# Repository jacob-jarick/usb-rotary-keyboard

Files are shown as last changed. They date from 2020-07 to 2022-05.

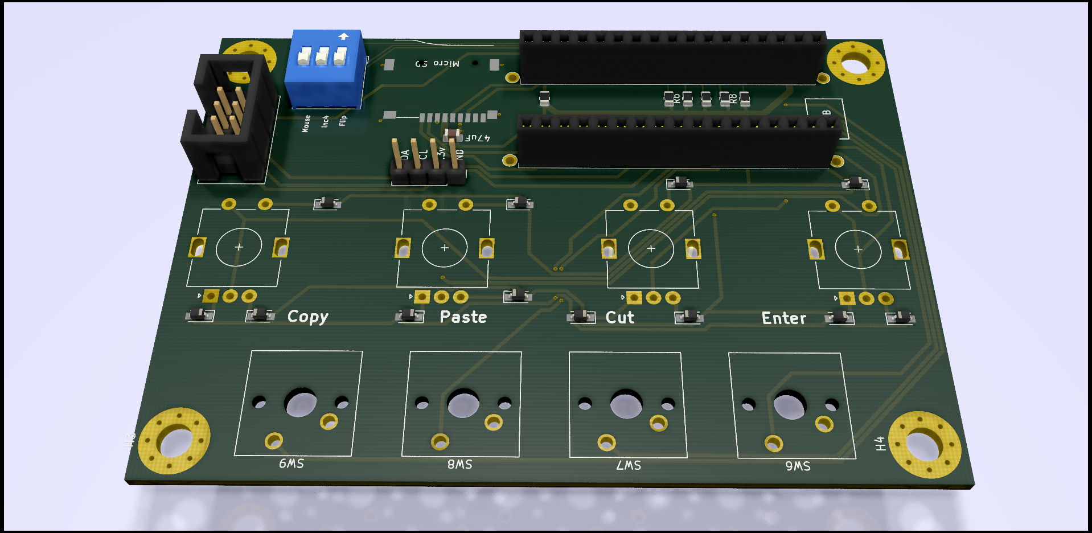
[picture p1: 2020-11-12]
pics/rot-kb.png

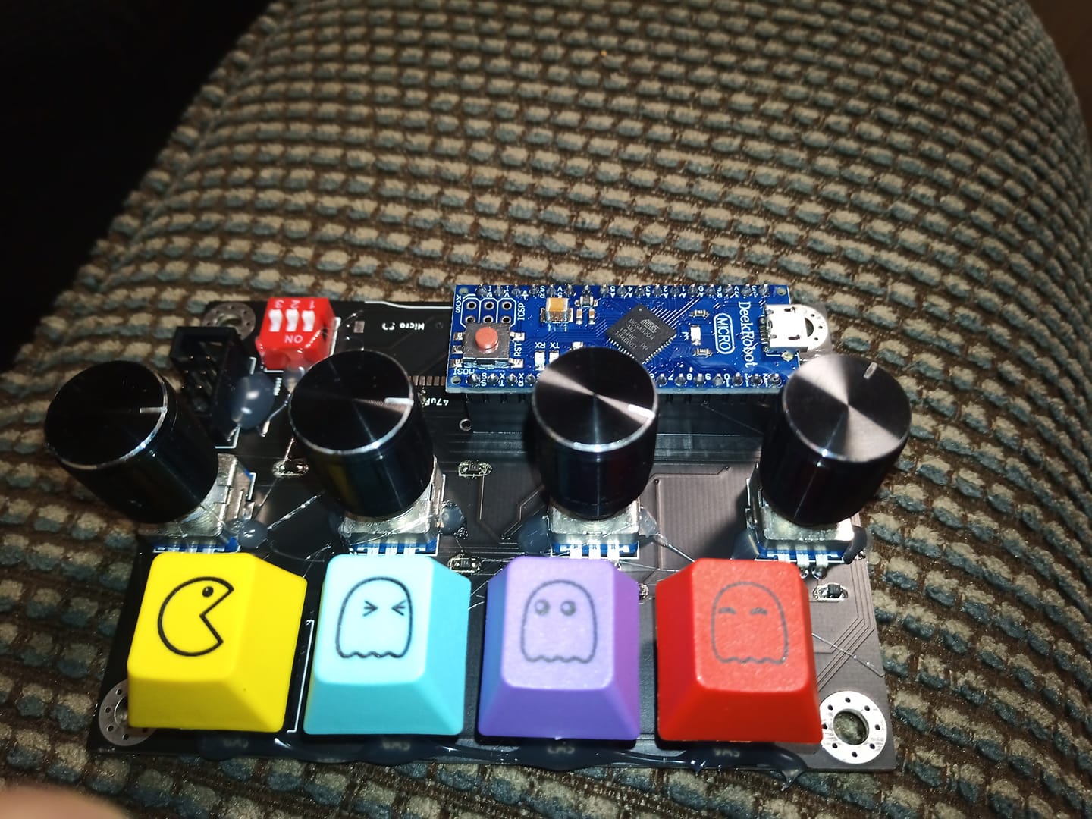
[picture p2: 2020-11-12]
pics/photo-v2.jpg

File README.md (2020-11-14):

# usb-rotary-keyboard

**Dip Switch Settings**

| Dip | On | Off |
|-----|---|---|
| 1 | 4 Step Rotary | 2 Step Rotary |
| 2 | Rotary Mouse  | Rotary Media Control |
| 3 | Alt Keys | Fx Keys |

note dip 3 change requires reset/ powercycle of keyboard.

**Cherry MX Key Functions**

| Key | Fuction | Alt Function |
|-----|---|---|
| 1 | F13 | Copy (CTRL+C)  |
| 2 | F14 | Cut (CTRL+X) |
| 3 | F15 | Paste (CTRL+V) |
| 4 | F16 | Paste Special  |

**Keyboard mode Mappings:**

| Rotary | Left | Right | Click |
|---|---|---|---|
| 1 | Volume Down | Volume Up | Mute |
| 2 | Media Previous | Media Next | Pause/Play |
| 3 | Media RWD | Media FFWD | Media Stop |
| 4 | KEY_LEFT_ARROW | KEY_RIGHT_ARROW | SPACE |

**Mouse mode Mappings:**

| Rotary | Left | Right | Click |
|---|---|---|---|
| 1 | Left | Right | Press/Release |
| 2 | Down | Up | Click |
| 3 | Left Up  | Right Down | Right Click |
| 4 | Right Up | Left Down  | Middle Click  |

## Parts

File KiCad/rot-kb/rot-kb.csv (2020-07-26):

Comment | Designator | Footprint | LCSC
47uF | C1 | Capacitor_SMD:C_0805_2012Metric
1N4148W | D8,D7,D12,D4,D3,D10,D6,D5,D11,D2,D1,D9 | Diode_SMD:D_SOD-323_HandSoldering
MountingHole_Pad | H1,H2 | MountingHole:MountingHole_4.3mm_M4_Pad_Via
Conn_02x03_Odd_Even | J1 | Connector_IDC:IDC-Header_2x03_P2.54mm_Vertical
Conn_01x04_Female | J2 | Connector_PinHeader_2.54mm:PinHeader_1x04_P2.54mm_Vertical
Digital | P1 | Socket_Arduino_Micro:Socket_Strip_Arduino_1x17
Analog | P2 | Socket_Arduino_Micro:Socket_Strip_Arduino_1x17
CONN_01X01 | P3,P4,P5,P6 | Socket_Arduino_Micro:1pin_Micro
ST-TF-003A | P7 | ST-TF-003A:SUNTECH_ST-TF-003A
10k | R2,R1,R3,R4 | Resistor_SMD:R_0805_2012Metric
Rotary_Encoder_Switch | SW1,SW3,SW4,SW2 | Rotary_Encoder:RotaryEncoder_Alps_EC11E-Switch_Vertical_H20mm
SW_DIP_x03 | SW5 | Button_Switch_THT:SW_DIP_SPSTx03_Slide_9.78x9.8mm_W7.62mm_P2.54mm

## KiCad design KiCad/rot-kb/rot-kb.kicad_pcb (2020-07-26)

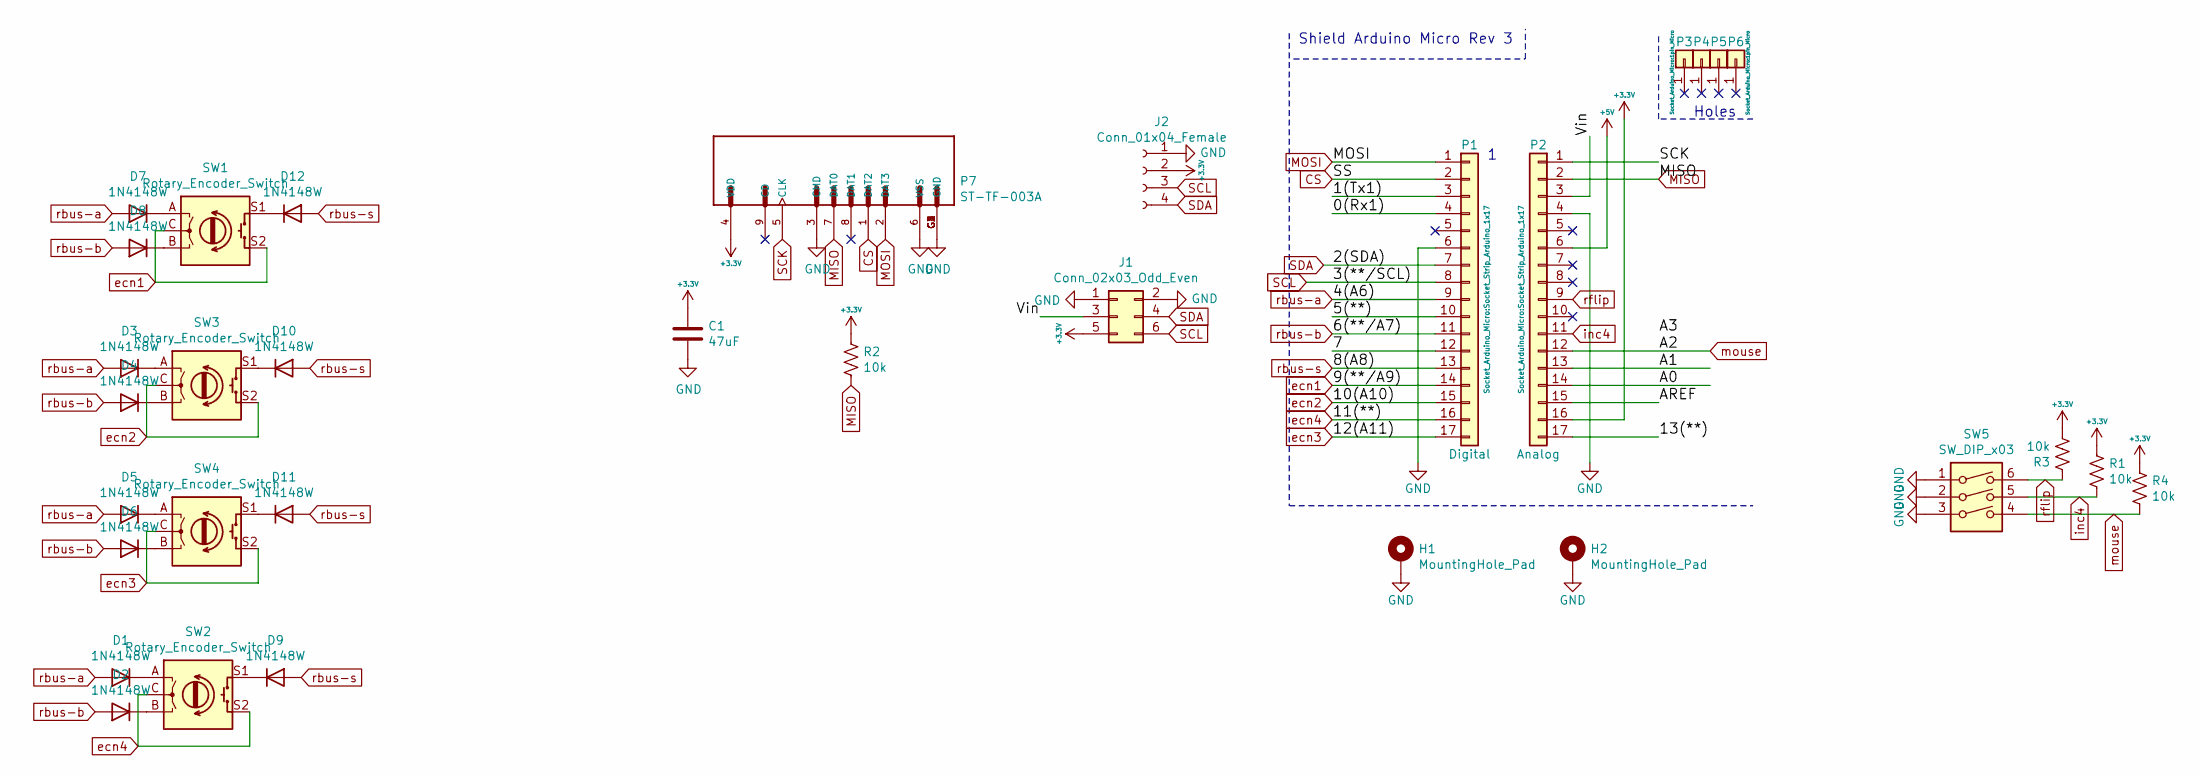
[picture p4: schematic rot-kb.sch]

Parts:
C1: 47uF; C_0805_2012Metric
D1, D2, D3, D4, D5, D6, D7, D8, D9, D10, D11, D12: 1N4148W; D_SOD-323_HandSoldering
H1, H2: MountingHole_Pad; MountingHole_4.3mm_M4_Pad_Via
J1: Conn_02x03_Odd_Even; IDC-Header_2x03_P2.54mm_Vertical
J2: Conn_01x04_Female; PinHeader_1x04_P2.54mm_Vertical
P1: Digital; Socket_Strip_Arduino_1x17
P2: Analog; Socket_Strip_Arduino_1x17
P3, P4, P5, P6: CONN_01X01; 1pin_Micro
P7: ST-TF-003A; SUNTECH_ST-TF-003A
R1, R2, R3, R4: 10k; R_0805_2012Metric
SW1, SW2, SW3, SW4: Rotary_Encoder_Switch; RotaryEncoder_Alps_EC11E-Switch_Vertical_H20mm
SW5: SW_DIP_x03; SW_DIP_SPSTx03_Slide_9.78x9.8mm_W7.62mm_P2.54mm

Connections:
+3V3: C1.1, J1.5, J2.2, P2.16, P7.4 (VDD), R1.1, R2.1, R3.2, R4.1
+5V: P2.6
/0(Rx1): P1.4
/1(Tx1): P1.3
/5(**): P1.10
/7: P1.12
/13(**): P2.17
/A0: P2.14
/A1: P2.13
/AREF: P2.15
/Vin: J1.3, P2.3
CS: P1.2, P7.1 (DAT2)
GND: C1.2, H1.1, H2.1, J1.1, J1.2, J2.1, P1.6, P2.4, P7.3 (CMD), P7.6 (VSS), P7.G1 (GND), P7.G2 (GND), P7.G3 (GND), P7.G4 (GND), SW5.1, SW5.2, SW5.3
MISO: P2.2, P7.7 (DAT0), R2.2
MOSI: P1.1, P7.2 (DAT3)
unnamed: D1.1 (K), SW2.A
unnamed: D2.1 (K), SW2.B
unnamed: D3.1 (K), SW3.A
unnamed: D4.1 (K), SW3.B
unnamed: D5.1 (K), SW4.A
unnamed: D6.1 (K), SW4.B
unnamed: D7.1 (K), SW1.A
unnamed: D8.1 (K), SW1.B
unnamed: D9.1 (K), SW2.S1
unnamed: D10.1 (K), SW3.S1
unnamed: D11.1 (K), SW4.S1
unnamed: D12.1 (K), SW1.S1
SCK: P2.1, P7.5 (CLK)
SCL: J1.6, J2.3, P1.8
SDA: J1.4, J2.4, P1.7
ecn1: P1.14, SW1.C, SW1.S2
ecn2: P1.15, SW3.C, SW3.S2
ecn3: P1.17, SW4.C, SW4.S2
ecn4: P1.16, SW2.C, SW2.S2
inc4: P2.11, R1.2, SW5.5
mouse: P2.12, R4.2, SW5.4
rbus-a: D1.2 (A), D3.2 (A), D5.2 (A), D7.2 (A), P1.9
rbus-b: D2.2 (A), D4.2 (A), D6.2 (A), D8.2 (A), P1.11
rbus-s: D9.2 (A), D10.2 (A), D11.2 (A), D12.2 (A), P1.13
rflip: P2.9, R3.1, SW5.6

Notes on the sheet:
Shield Arduino Micro Rev 3
Holes

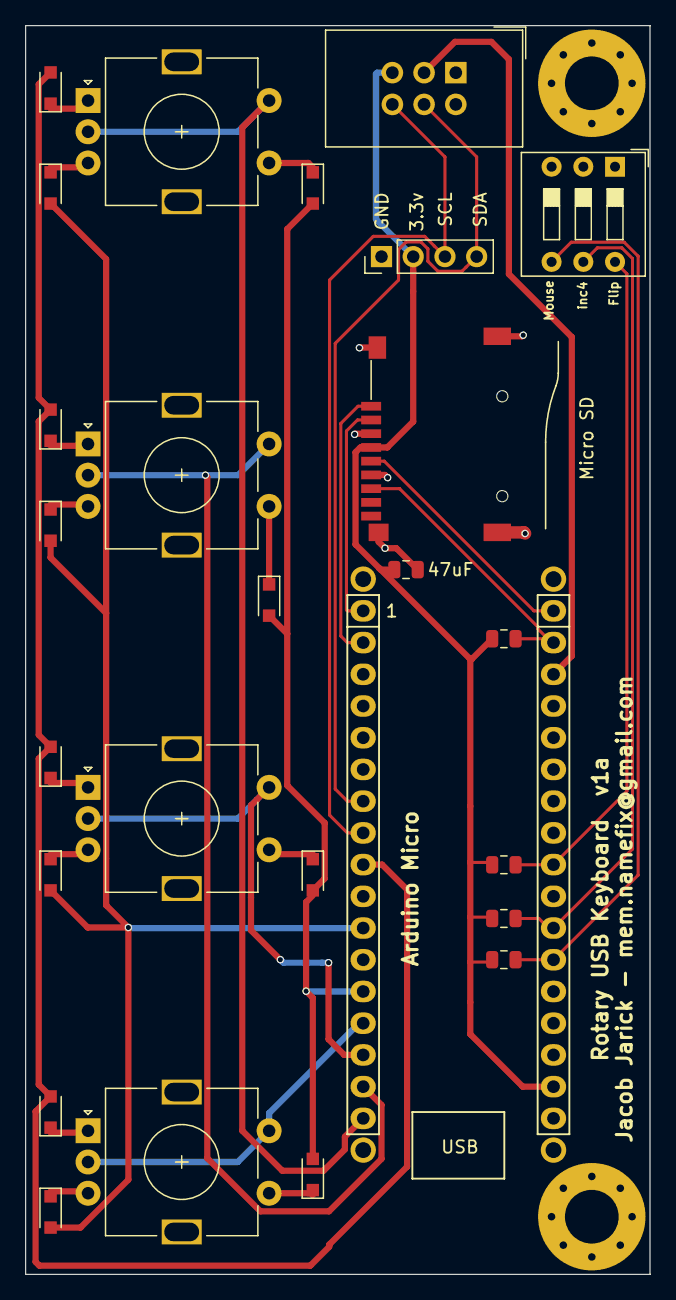
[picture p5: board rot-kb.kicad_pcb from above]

Board: 2 copper layers, 50.0 x 100.0 mm, 33 parts (0 on the bottom side), 31 nets.

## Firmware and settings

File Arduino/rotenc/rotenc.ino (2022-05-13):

/*  Version 1
    4x Rotary Encoder USB keyboard
    Board target: Arduino Micro Pro
    Written by Jacob Jarick
    mem.namefix@gmail.com
   https://github.com/jacob-jarick/usb-rotary-keyboard

   board: sparkfun pro micro
   5v 16Mhz
   board arduino git repo:
   https://raw.githubusercontent.com/sparkfun/Arduino_Boards/master/IDE_Board_Manager/package_sparkfun_index.json

*/

#include "HID-Project.h"
#include <CommonBusEncoders.h>
CommonBusEncoders encoders(4, 6, 8, 4);

const bool skyrim_photos = 1;

const uint8_t keya = 19;
const uint8_t keyb = 7;
const uint8_t keyc = 22;
const uint8_t keyd = 5;

const int sky_inc = 300;

const uint8_t dip1 = 23; // rflip (now paste special) - triggers keyC
const uint8_t dip2 = 21; // mouse
const uint8_t dip3 = 20; // inc4

const uint8_t key_debounce = 150;

unsigned long keysleep[8] = {0, 0, 0, 0, 0, 0, 0, 0};

// set to match your encoders.
uint8_t rsteps = 2;

// these bools will be set via jumpers
//bool alt_steps = 1; // 0 = 2 steps, 1 = 4 steps
bool rmouse = 0; // worlds most awkward mouse - etch a sketch style

// internal bools

bool mousepress = 0;

void setup()
{
  pinMode(keya, INPUT);
  pinMode(keyb, INPUT);
  pinMode(keyc, INPUT);
  pinMode(keyd, INPUT);

  pinMode(dip1, INPUT);
  pinMode(dip2, INPUT);
  pinMode(dip3, INPUT);

  encoders.setDebounce(16);
  encoders.resetChronoAfter(1000);

  if (digitalRead(dip3))
    rsteps = 4;

  encoders.addEncoder(1, rsteps, 12, 1, 100,  199);
  encoders.addEncoder(2, rsteps, 11, 1, 200, 299);
  encoders.addEncoder(3, rsteps, 10, 1, 300,  399);
  encoders.addEncoder(4, rsteps, 9, 1, 400, 499);

  Consumer.begin();
  Keyboard.begin();
  Mouse.begin();

  Serial.begin(19200);
}

void loop()
{
  // ====================================================
  // read dip switches

  rmouse = digitalRead(dip2);
  uint8_t alt_keymap = digitalRead(dip1);

  // ====================================================
  // read keys

  if (keysleep[0] < millis() && !digitalRead(keya))
  {
    keysleep[0] = millis() + key_debounce;

    if (skyrim_photos)
    {
      Mouse.move(sky_inc * 2, 0, 0);
      delay(100);
      macro_shift_fx(12);
      keysleep[0] = millis() + 750;
    }
    else if (alt_keymap)
      macro_copy();
    else
      macro_shift_fx(1);
  }
  if (keysleep[1] < millis() && !digitalRead(keyb))
  {
    keysleep[1] = millis() + key_debounce;

    if (skyrim_photos)
    {
      Mouse.move(0, sky_inc * -1, 0);
      delay(100);
      macro_shift_fx(12);
      keysleep[1] = millis() + 750;
    }
    else if (alt_keymap)
      macro_cut();
    else
      macro_shift_fx(2);
  }
  if (keysleep[2] < millis() && !digitalRead(keyc))
  {
    keysleep[2] = millis() + key_debounce;

    if (alt_keymap)
      macro_paste();
    else
      macro_shift_fx(3);
  }
  if (keysleep[3] < millis() && !digitalRead(keyd))
  {
    keysleep[3] = millis() + key_debounce;

    if (alt_keymap)
      macro_paste_special();
    else
      macro_shift_fx(4);
  }

  // ====================================================
  // read encoders

  int index = encoders.readAll();
  if (index == 0)
    return;

  Serial.println(index);

  // ----------------------------------------
  // Rotary 1 - media vol, up, down, mute

  if (keysleep[4] < millis())
  {
    if (index == 101)
    {
      keysleep[4] = millis() + key_debounce;

      if (rmouse)
      {
        if (skyrim_photos)
        {
          Mouse.move(sky_inc * 2, 0, 0);
          delay(100);
          macro_shift_fx(12);
        }
        else
        {
          Mouse.move(5, 0, 0);
        }
      }
      else
        Consumer.write(MEDIA_VOLUME_UP);
    }
    else if (index == 100)
    {
      keysleep[4] = millis() + key_debounce;

      if (rmouse)
      {
        if (skyrim_photos)
        {
          Mouse.move(sky_inc * -2, 0, 0);
          delay(100);
          macro_shift_fx(12);
        }
        else
          Mouse.move(-5, 0, 0);
      }
      else
        Consumer.write(MEDIA_VOLUME_DOWN);
    }
    else if (index == 199)
    {
      keysleep[4] = millis() + key_debounce;

      if (rmouse)
        mousetoggle();
      else
        Consumer.write(MEDIA_VOLUME_MUTE);
    }
  }

  // ----------------------------------------
  // Rotary 2 - media, next, prev, play/pause

  if (keysleep[5] < millis())
  {
    if (index == 201)
    {
      keysleep[5] = millis() + key_debounce;

      if (rmouse)
      {
        if (skyrim_photos)
        {
          Mouse.move(0, sky_inc, 0);
          delay(100);
          macro_shift_fx(12);
        }
        else
          Mouse.move(0, 5, 0);
      }
      else
        Consumer.write(MEDIA_NEXT);
    }
    else if (index == 200)
    {
      keysleep[5] = millis() + key_debounce;
      if (rmouse)
      {
        if (skyrim_photos)
        {
          Mouse.move(0, sky_inc * -1, 0);
          delay(100);
          macro_shift_fx(12);
        }
        else
          Mouse.move(0, -5, 0);
      }
      else
        Consumer.write(MEDIA_PREVIOUS);
    }
    else if (index == 299)
    {
      keysleep[5] = millis() + key_debounce;
      if (rmouse)
      {
        Mouse.release();
        Mouse.click();
      }
      else
        Consumer.write(MEDIA_PLAY_PAUSE);
    }
  }
  // ----------------------------------------
  // Rotary 3 - media ffwd, rwd, stop

  if (keysleep[6] < millis())
  {
    if (index == 301)
    {
      keysleep[6] = millis() + key_debounce;

      if (rmouse)
        Mouse.move(5, 5, 0);
      else

        Consumer.write(MEDIA_FAST_FORWARD);
    }
    else if (index == 300)
    {
      keysleep[6] = millis() + key_debounce;

      if (rmouse)
        Mouse.move(-5, -5, 0);
      else
        Consumer.write(MEDIA_REWIND);
    }
    else if (index == 399)
    {
      keysleep[6] = millis() + key_debounce;

      if (rmouse)
      {
        Mouse.release();
        Mouse.click(MOUSE_RIGHT);
      }
      else
        Consumer.write(MEDIA_STOP);
    }
  }
  // ----------------------------------------
  // Rotary 4 - mplayer control

  if (keysleep[7] < millis())
  {
    if (index == 401)
    {
      keysleep[7] = millis() + key_debounce;

      if (rmouse)
        Mouse.move(-5, 5, 0);
      else
        Keyboard.write(KEY_RIGHT_ARROW);
    }
    else if (index == 400)
    {
      keysleep[7] = millis() + key_debounce;

      if (rmouse)
        Mouse.move(5, -5, 0);
      else
        Keyboard.write(KEY_LEFT_ARROW);
    }
    else if (index == 499)
    {
      keysleep[7] = millis() + key_debounce;

      if (rmouse)
      {
        Mouse.release();
        Mouse.click(MOUSE_MIDDLE);
      }
      else
        Keyboard.write(' ');
    }
  }
}

void mousetoggle()
{
  mousepress = !mousepress;

  if (mousepress)
    Mouse.press();
  else
    Mouse.release();
}


void macro_paste()
{
  Serial.println("C - Paste");
  Keyboard.press(KEY_LEFT_CTRL);
  Keyboard.press('v');
  delay(50);
  Keyboard.releaseAll();
}

void macro_cut()
{
  Serial.println("B - Cut");
  Keyboard.press(KEY_LEFT_CTRL);
  Keyboard.press('x');
  delay(50);
  Keyboard.releaseAll();
}

void macro_copy()
{
  Serial.println("A - Copy");
  Keyboard.press(KEY_LEFT_CTRL);
  Keyboard.press('c');
  delay(50);
  Keyboard.releaseAll();
}

void macro_paste_special()
{
  Serial.println("D - Paste Special");

  // jump to begining of form input/ line
  Keyboard.write(KEY_HOME);
  delay(50);

  // select contents of form input/ line
  Keyboard.press(KEY_LEFT_SHIFT);
  Keyboard.press(KEY_END);
  delay(50);

  Keyboard.releaseAll();
  delay(50);

  // delete contents
  Keyboard.write(KEY_DELETE);
  delay(50);

  // paste clipboard contents
  Keyboard.press(KEY_LEFT_CTRL);
  Keyboard.press('v');
  delay(50);
  Keyboard.releaseAll();
}

void macro_shift_fx(uint8_t fx)
{
  Serial.println("F" + String(fx));

  Keyboard.press(KEY_LEFT_SHIFT);

  if (fx == 1)
    Keyboard.press(KEY_F1);
  else if (fx == 2)
    Keyboard.press(KEY_F2);
  else if (fx == 3)
    Keyboard.press(KEY_F3);
  else if (fx == 4)
    Keyboard.press(KEY_F4);
  else if (fx == 12)
    Keyboard.press(KEY_F12);

  delay(50);
  Keyboard.releaseAll();
}
